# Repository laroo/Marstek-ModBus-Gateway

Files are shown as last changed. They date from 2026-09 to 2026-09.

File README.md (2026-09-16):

# Marstek ModBus Gateway



  

**Direct Ethernet-to-Modbus integration for Marstek battery systems, providing local monitoring and control via MQTT**

Marstek ModBus Gateway is a custom hardware gateway designed to bridge the Marstek Venus E v2.0 home battery energy storage system with Home Assistant and local automation systems via a hardwired Ethernet connection. Powered by an ESP32-ETH01 microcontroller and an RS485 transceiver, this dedicated PCB reads Modbus telemetry directly from the battery and translates it into MQTT messages for low-latency, cloud-free monitoring and active charge/discharge control.

## Key Features

- Hardwired Reliability: Utilizes the onboard Ethernet interface of the ESP32-ETH01 for fast, stable network communication without Wi-Fi dropouts.

- Direct Modbus to MQTT: Communicates with the Marstek Venus E v2.0 via RS485/Modbus RTU and publishes metrics and control entities to your local MQTT broker.

- Home Assistant Integration: Enables automatic MQTT discovery for seamless setup of battery state of charge (SoC), power flow, and charge/discharge overrides within Home Assistant.

- Compact Custom PCB: Integrates power regulation, RS485 transceiver protection/isolation, and clean mounting for the ESP32-ETH01 module.

## Technical Architecture

- MCU: ESP32-ETH01 (WT32-ETH01)

- Hardware Interface: RS485 (Modbus RTU)

- Network Protocol: Ethernet / MQTT (with Home Assistant MQTT Discovery)

- Target Device: Marstek Venus E v2.0 Battery System

## Primary Use Cases

- Off-peak grid charging and peak-shaving automated via Home Assistant MQTT triggers.

- Solar excess storage optimization and real-time power steering.

- Local telemetry logging and full battery management without relying on vendor cloud APIs.

## Changelog

v1.0
- Initial release

## MQTT Configuration

### MQTT Topics

TBD - will be updated when the gateway is fully implemented

```
marstek-modbus-gateway/state = CHARGING
```

### MQTT Commands

TBD - will be updated when the gateway is fully implemented

```
marstek-modbus-gateway/command = CHARGE
marstek-modbus-gateway/command = DISCHARGE
marstek-modbus-gateway/command = PAUSE
```

## Home Assistant Configuration

TODO

## Schematics and PCB

Used LibrePCB to design the schematics and PCB.

Schematic

PCB

Gerber files for the PCB can be found [here](librepcb/output/v1.0/gerber).

# Input/Output

| Pin | Direction | Function | Note |
|----|---|---|---|
| GPIO 2 | Input | Sensor 1 | Optional sensor |

## Code

The firmware is built on the Arduino framework using PlatformIO and implements a robust gate control system with the following key features:

- **MQTT Integration**: Remote control and status monitoring via MQTT over Ethernet (W5500)
- **Visual Feedback**: LED system indicating communication status
- **ModBus**: RS485 communication for industrial automation
- **Diagnostics**: Serial output at 115200 baud for debugging and monitoring

### Platform IO Setup

```
pyenv local 3.13
python -m venv .venv
source .venv/bin/activate
pip install -r requirements.txt
```

### Build

```
pio run
```

### Test

```
pio test -v -e native
```

Run a single test:

```
TEST_FILTER=test_mytest pio test -v -e native
```

### Upload (Serial)

```
pio run --target upload -v
```

### Wokwi Simulation

The firmware can be simulated using Wokwi.

#### Installation

To install the Wokwi CLI:

```
curl -L https://wokwi.com/ci/install.sh | sh
```

#### Running the Simulation

To run the simulation:

Build the ESP32 firmware for Wokwi:

```
pio run --environment esp32_wokwi
```

Build custom RS485 chip:

```
wokwi-cli chip compile wokwi/max485-marstek.chip.c
```

Run simulation:

```
wokwi-cli wokwi
```

Run linter:

```
wokwi-cli lint wokwi
```

### OTA (Over-the-Air) Update

The firmware includes [ElegantOTA](https://github.com/ayushsharma82/ElegantOTA) for wireless firmware updates over the network.

1. Open a browser and navigate to `http://<device-ip>/update`
2. Authenticate with the configured `OTA_USERNAME` and `OTA_PASSWORD`
3. Select the firmware binary (`.pio/build/esp32/firmware.bin`) and upload

OTA credentials are set as compile-time build flags in `private_config.ini`:

```ini
'-D OTA_USERNAME=youruser'
'-D OTA_PASSWORD=yourpassword'
```

### Web Interface

The device runs an HTTP server on port 80 with the following endpoints:

| Endpoint | Description |
|---|---|
| `/` | Device identification |

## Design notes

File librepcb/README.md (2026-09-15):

# My first pcb

## Description

This is a [LibrePCB](https://librepcb.org) project!
Just edit this file to add a description about it.

## License

No license set.

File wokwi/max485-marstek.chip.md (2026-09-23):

# MAX485 Marstek emulator chip

Wokwi custom chip that emulates the Modbus RTU slave side of a **Marstek Venus E v2.0** battery system behind an RS-485 transceiver.

## Build

```bash
wokwi-cli chip compile wokwi/max485-marstek.chip.c
```

## Run simulation

```bash
# Build the ESP32 firmware for Wokwi first
pio run --environment esp32_wokwi

# Compile and run the custom chip simulation
wokwi-cli chip compile wokwi/max485-marstek.chip.c
wokwi-cli wokwi
```

## Supported Modbus registers

Function code **0x03** (Read Holding Registers) and **0x06** (Write Single Register) are implemented.

| Register (DEC) | Register (HEX) | Name | Type | Implemented | Notes |
|---|---|---|---|---|---|
| 31000 | `0x7918` | Device name | `char[20]` | Yes | Returns `"BI_2.5_2.5"` padded with zeros; read quantity must be `10` registers |
| 30400 | `0x76C0` | Software version | `u16`, 0.01 | Yes | Returns `0x0067` (103 -> 1.03); read quantity must be `1` |
| 30401 | `0x76C1` | Firmware version | `u16` | Yes | Returns `0x0099` (153); read quantity must be `1` |
| 30402 | `0x76C2` | Device MAC address | `char[12]` | Yes | Returns `"A1B2C3D4E5F6"`; read quantity must be `6` registers |
| 42000 | `0xA410` | RS485 control mode | `u16` | Yes | R/W: `0x55AA` enable, `0x55BB` disable |
| 42010 | `0xA41A` | Forcible charge/discharge | `u16` | Yes | R/W: `0` stop, `1` charge, `2` discharge |
| 42020 | `0xA424` | Forcible charge power | `u16`, W | Yes | R/W: `0-2500` |
| 42021 | `0xA425` | Forcible discharge power | `u16`, W | Yes | R/W: `0-2500` |
| 32200 | `0x7DC8` | AC voltage | `u16`, 0.1 V | Yes | Returns `2300` (230.0 V); supports quantity `1` or `5` |
| 32201 | `0x7DC9` | AC current | `u16`, 0.01 A | Yes | Magnitude calculated from active power / 230 V |
| 32202 | `0x7DCA` | AC power | `s32`, W | Yes | Negative when charging, positive when discharging; based on forced power setting |
| 32204 | `0x7DCC` | AC frequency | `u16`, 0.01 Hz | Yes | Returns `5000` (50.00 Hz) |
| 32100 | `0x7D64` | Battery voltage (average) | `u16`, 0.01 V | Yes | Returns `5120` (51.20 V); supports quantity `1` or `4` |
| 32101 | `0x7D65` | Battery current (average) | `s16`, 0.01 A | Yes | Returns `1502` (15.02 A); read quantity must be `1` |
| 32102 | `0x7D66` | Battery power | `s32`, 1 W | Yes | Returns `2500` W; spans registers `32102` and `32103`; read quantity must be `2` |

Reading address `0x7D64` with quantity `4` returns voltage, current and power in a single response (registers `32100..32103`).

## Serial commands (ESP32 firmware)

The ESP32 firmware (`src/Marstek-ModBus-Gateway.ino.cpp`) accepts these commands over USB serial:

| Command | Action |
|---|---|
| `charge=<watts>` | Enable RS485 control mode, set charge power, start charging |
| `discharge=<watts>` | Enable RS485 control mode, set discharge power, start discharging |
| `charge=0` / `discharge=0` / `stop` | Stop charge/discharge and disable RS485 control mode |

Example: `charge=2000` writes `0x55AA` to `42000`, `2000` to `42020` and `1` to `42010`.

### LED feedback

- **Green LED** blips briefly on each successful Modbus telemetry poll and executed command.
- **Red LED** is solid while a Modbus or network error is present.
- LEDs are active-low.

## Findings and open issues

1. **Baud rate**: chip and ESP32 firmware are now both set to **115200 baud, 8N1**, matching the Marstek datasheet.
2. **Static/example values**: all register values are hard-coded examples taken from the CSV. Telemetry (voltage/current/power) does not yet change when charge/discharge control is active.
3. **FC 0x03 and FC 0x06 supported**: read holding registers and write single register are implemented. Other function codes (0x04, 0x10, etc.) return an illegal-function exception.
4. **RE/DE pins not emulated**: the chip does not model the MAX485 direction-control behaviour; it simply receives on `DI` and transmits on `RO`. This matches the Wokwi simulation because the ESP32 already drives RE/DE.
5. **CRC validation**: incoming frames are CRC-checked and responses include a valid Modbus RTU CRC-16.
6. **Firmware loop**: `src/Marstek-ModBus-Gateway.ino.cpp` reads telemetry every 4 s and processes serial commands (`charge=<watts>`, `discharge=<watts>`, `stop`) immediately.

## TODO — implement all function ID registers

Based on `specs/Modbus Table - Modbus Datasheet.csv`:

### Read holding registers (FC 0x03)

- [x] 31000 — Device name
- [x] 32100 — Battery voltage (average)
- [x] 32101 — Battery current (average)
- [x] 32102 — Battery power
- [ ] 30000..30010 — Average/grid measurements
- [ ] 30100, 30200, 30300..30303 — Status / WiFi / BT / Cloud
- [ ] 30399 — BMS version (same as 31102)
- [x] 30400, 30401, 30402 — Software/firmware version + MAC
- [ ] 30500..30800 — Misc status
- [ ] 31100..31102 — Soft/firmware/BMS version
- [ ] 31200 — SN code
- [ ] 32104, 32105 — Battery SoC / total energy
- [x] 32200..32204 — AC measurements
- [ ] 32300..32302 — AC off-grid measurements
- [ ] 33000..33010 — Energy counters
- [ ] 35000..35011 — Temperatures
- [ ] 35100 — Inverter state
- [ ] 35110..35112 — Charge/discharge limits
- [ ] 36000..36104 — Alarm / fault words
- [ ] 37000..37013 — Misc / cell information
- [ ] 41000, 41001, 41010, 41100, 41200, 41500, 41516 — Control / config
- [x] 42000, 42010..42021 — RS485 control / force charge-discharge
- [ ] 43000..43129 — Time-of-use settings
- [ ] 44000..44100, 45603, 45604 — Cutoff / grid standards / unknown

### Write functions

- [ ] FC 0x06 — Write single register (e.g. 41000 restart, 41100 Modbus address)
- [ ] FC 0x10 — Write multiple registers (e.g. time-of-use slots, WiFi credentials)

## Reference

- Modbus register table: `../specs/Modbus Table - Modbus Datasheet.csv`
- ESP32 firmware: `../src/Marstek-ModBus-Gateway.ino.cpp`

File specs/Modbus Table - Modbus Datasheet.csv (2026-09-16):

This document is based on ‘Duravolt Plug-In thuisbatterij 485 protocol v1.1’, available from https://duravolt.nl/wp-content/uploads/Duravolt-Plug-in-Battery-Modbus.pdf (checked on 14-08-2025). Changes made to the document are highlighted in red (except for typo’s). Scans are made on firmware v153 and BMS v213.
Protocol specification:
Standard Modbus RTU Protocol
Modbus default Address: 1
baud:115200, 8bit, No parity bit, 1bit Stopbit
Quirk: If register contains more than 2 bytes of data, data should be read in one function call instead of consecutive calls to consecutive registers or it will be invalid. Therefore if any data is present, one can deduct where a range must be split. If data is zeroes, the range is left and appended with a ‘?’.
Version | Date |  | Change
v2.0 | 07/11/25 |  | Create document based on Duravolt document
v2.1 | 07/16/25 |  | Added registers 30001, 30002, 30004, 30005, 30006, 30008, 30009, 30010, 30300, 30301, 30302, 30303, 37004, 37005, 37006, 37007, 37008, 41010. Added notes on 30007, 30100, 30600, 36101, 37013
v2.2 | 08/14/25 |  | Added observerations for some unknown registers. Changed error registers based on educated guesses. Identified register 41001. Added notes for registers 41500, 41516, 43000, 45603, 45604.
Function | ID (DEC) | ID (HEX) | Name | Bytes | Value type | Gain / Unit | Description | Read out | Meaning
0x03 | 30000 | 7530 | Unknown | 2 | unknown | unknown | 142-145 (DEC) osc, mostly 143-144, more activity 144-145 when charging
 | 30001 | 7531 | Battery voltage (average) | 2 | u16 | 0,01 V | Same as 32100 | 5120 (DEC) | 51,2 V
 | 30002 | 7532 | Battery current (average) | 2 | s16 | 0,01 A | Same as 32101 | 1502 (DEC) | 15,02 A
 | 30003 | 7533 | Unknown | 2 | unknown | unknown | Corresponds to AC Voltage added with Power?
 | 30004 | 7534 | AC voltage | 2 | u16 | 0,1 V | Same as 32200 | 2200 (DEC) | 220 V
 | 30005 | 7535 | AC current | 2 | u16 | 0,01 A | Same as 32201 | 350 (DEC) | 3,5 A
 | 30006 | 7536 | AC offgrid voltage | 2 | u16 | 0,1 V | Same as 32300 | 2200 (DEC) | 220 V
 | 30007 | 7537 | Unknown | 2 | unknown | unknown | Related to status? Rapid osc. between 1 and 2 when charge, 1 when backup, 0 when idle. Also random osc. between 0 and 1 when idle
 | 30008 | 7538 | Internal MOS1 temperature | 2 | s16 | 0,1 °C | Same as 35001 | 257 (DEC) | 25,7 °C
 | 30009 | 7539 | Internal MOS2 temperature | 2 | s16 | 0,1 °C | Same as 35002 | 257 (DEC) | 25,7 °C
 | 30010 | 753A | Internal temperature | 2 | s16 | 0,1 °C | Same as 35000 | 373 (DEC) | 37,3 °C
 | 30100 | 7594 | Unknown | 8? | unknown | unknown | Same as 36100
 | 30200 | 75F8 | Unknown | 8? | unknown | unknown | Always seen 0
 | 30300 | 765C | WiFi status | 2 | u16 | / | 0:disconnected, 1:connected
 | 30301 | 765D | BT status | 2 | u16 | / | 0:off, 1:active_after_boot?stand-by?, 2:connected, 3:active
 | 30302 | 765E | Cloud status | 2 | u16 | / | 0:disconnected, 1:connected, Approx 5 min delay after connection loss
 | 30303 | 765F | WiFi Signal Strength | 2 | u16 | dBm
 | 30399 | 76BF | BMS version (HEX) | 2 | u16 | / | Same as 31102 (but in HEX) | 0xD5 (HEX) | 213
 | 30400 | 76C0 | Software version (HEX) | 2 | u16 | 0,01 | Same as 31100 (but in HEX) | 0x67 (HEX) | 1,03
 | 30401 | 76C1 | Firmware version (HEX) | 2 | u16 | / | Same as 31101 (but in HEX) | 0x99 (HEX) | 153
 | 30402 | 76C2 | Device MAC address | 12 | char | /
 | 30500 | 7724 | Unknown | 2 | unknown | unknown | Always seen 1
 | 30600 | 7788 | Unknown | 2 | unknown | unknown | 00Ca when idle, 00cc/00cb when bypass, 0xd4 when backup, 00ce when (dis)charge, sometime 0xd7 when empty followed by charge, or 0xd8
 | 30700 | 77EC | Unknown | 2 | unknown | unknown | Changed to 1 some time after empty and stayed 1 even after full. Turned 0 after messing around when 100 soc, self-test fault?
 | 30800 | 7850 | Communication module firmware version | 12 | char | /
 | 31000 | 7918 | Device name | 20 | char | / | Typically: BI_2.5_2.5 or AC01
 | 31100 | 797C | Soft version | 2 | u16 | 0,01 |  | 103 (DEC) | 1,03
 | 31101 | 797D | Firmware version | 2 | u16 | / |  | 153 (DEC) | 153
 | 31102 | 797E | BMS version | 2 | u16 | / |  | 213 (DEC) | 213
 | 31200 | 79E0 | SN code | 20 | char | / | Typically: [empty]
 | 32100 | 7D64 | Battery voltage (average) | 2 | u16 | 0,01 V |  | 5120 (DEC) | 51,2 V
 | 32101 | 7D65 | Battery current (average) | 2 | s16 | 0,01 A |  | 1502 (DEC) | 15,02 A
 | 32102 | 7D66 | Battery power | 4 | s32 | 1 W |  | 2500 (DEC) | 2500 W
 | 32104 | 7D68 | Battery SOC | 2 | u16 | 1 % |  | 500 (DEC) | 50 %
 | 32105 | 7D69 | Battery total energy | 2 | u16 | 0,001 kWh | Unit: v148: 0.001 / v147: 0.01 | 2500 (DEC) | 2,5 kWh
 | 32200 | 7DC8 | AC voltage | 2 | u16 | 0,1 V |  | 2200 (DEC) | 220 V
 | 32201 | 7DC9 | AC current | 2 | u16 | 0,01 A |  | 350 (DEC) | 3,5 A
 | 32202 | 7DCA | AC power | 4 | s32 | W | Positive value means feeds power into the grid | 1000 (DEC) | 1000 W
 | 32204 | 7DCC | AC frequency | 2 | u16 | 0,01 Hz |  | 5000 (DEC) | 50 Hz
 | 32300 | 7E2C | AC offgrid voltage | 2 | u16 | 0,1 V |  | 2200 (DEC) | 220 V
 | 32301 | 7E2D | AC offgrid current | 2 | u16 | 0,1 A |  | 350 (DEC) | 3,5 A
 | 32302 | 7E2E | AC offgrid power | 4 | s32 | W |  | 1000 (DEC) | 1000 W
 | 33000 | 80E8 | Total charging energy | 4 | u32 | 0,01 kWh |  | 100000 (DEC) | 1000 kWh
 | 33002 | 80EA | Total discharging energy | 4 | u32 | 0,01 kWh |  | 100000 (DEC) | 1000 kWh
 | 33004 | 80EC | Daily charging energy | 4 | u32 | 0,01 kWh | Updated daily at 00:00 | 500 (DEC) | 5 kWh
 | 33006 | 80EE | Daily discharging energy | 4 | u32 | 0,01 kWh | Updated daily at 00:00 | 2000 (DEC) | 20 kWh
 | 33008 | 80F0 | Monthly charging energy | 4 | u32 | 0,01 kWh | Updated on 1st of each month | 10000 (DEC) | 100 kWh
 | 33010 | 80F2 | Monthly discharging energy | 4 | u32 | 0,01 kWh | Updated on 1st of each month | 10000 (DEC) | 100 kWh
 | 35000 | 88B8 | Internal temperature | 2 | s16 | 0,1 °C |  | 373 (DEC) | 37,3 °C
 | 35001 | 88B9 | Internal MOS1 temperature | 2 | s16 | 0,1 °C |  | 257 (DEC) | 25,7 °C
 | 35002 | 88BA | Internal MOS2 temperature | 2 | s16 | 0,1 °C |  | 257 (DEC) | 25,7 °C
 | 35010 | 88C2 | Max cell temperature | 2 | s16 | 0,1 °C | Unit: BMS v213: 1°C | -32 (DEC) | -3,2 °C
 | 35011 | 88C3 | Min cell temperature | 2 | s16 | 0,1 °C | Unit: BMS v213: 1°C | 400 (DEC) | 40 °C
 | 35100 | 891C | Inverter state | 2 | u16 | / | 0:sleep, 1:stand-by, 2:charge, 3:discharge, 4:backup mode, 5:OTA upgrade, 6:bypass | 2 | Charge
 | 35110 | 8926 | Battery charge voltage limit | 2 | u16 | 0,1 V | Typically: 57,1 V | 120 (DEC) | 12 V
 | 35111 | 8927 | Battery charge current limit | 2 | u16 | 0,1 A |  | 50 (DEC) | 5 A
 | 35112 | 8928 | Battery discharge current limit | 2 | u16 | 0,1 A |  | 50 (DEC) | 5 A
 | 36000 | 8CA0 | Unknown | 2 | unknown | unknown | Alarm/fault register
 | 36001 | 8CA1 | Unknown | 2 | unknown | unknown | Alarm/fault register
 | 36100 | 8D04 | Alarm word | 2 | bit | / | See below (educated guess, see notes below)
 |  |  | PLL Abnormal restart | 0 | bit | / | 0:normal, 1:abnormal
 |  |  | Overtemperature limit | 1 | bit | / | 0:normal, 1:abnormal
 |  |  | Low temperature limit | 2 | bit | / | 0:normal, 1:abnormal
 |  |  | Fan abnormal warning | 3 | bit | / | 0:normal, 1:abnormal
 |  |  | Low battery SoC warning | 4 | bit | / | 0:normal, 1:abnormal
 |  |  | Output overcurrent warning | 5 | bit | / | 0:normal, 1:abnormal
 |  |  | Abnormal line sequence detection | 6 | bit | / | 0:normal, 1:abnormal
 | 36101 | 8D05 | Fault word | 2 | bit | / | See below (educated guess, see notes below)
 |  |  | Hardware bus overvoltage | 0 | bit | / | 0:normal, 1:abnormal
 |  |  | Hardware output overcurrent | 1 | bit | / | 0:normal, 1:abnormal
 |  |  | Hardware trans overcurrent | 2 | bit | / | 0:normal, 1:abnormal
 |  |  | Hardware battery overcurrent | 3 | bit | / | 0:normal, 1:abnormal
 |  |  | Hardware protection | 4 | bit | / | 0:normal, 1:abnormal
 |  |  | Output overcurrent warning | 5 | bit | / | 0:normal, 1:abnormal
 |  |  | High voltage bus overvoltage | 6 | bit | / | 0:normal, 1:abnormal
 |  |  | High voltage bus undervoltage | 7 | bit | / | 0:normal, 1:abnormal
 |  |  | Overpower protection | 8 | bit | / | 0:normal, 1:abnormal
 |  |  | FSM abnormal | 9 | bit | / | 0:normal, 1:abnormal
 |  |  | Overtemperature protection | 10 | bit | / | 0:normal, 1:abnormal
 |  |  | Inverter soft start timeout | 11 | bit | / | 0:normal, 1:abnormal
 | 36102 | 8D06 | Unknown | 2 | unknown | unknown | Alarm/fault register
 | 36103 | 8D07 | Fault word | 1 | bit | / | See below (educated guess, see notes below)
 |  |  | Battery overvoltage | 0 | bit | / | 0:normal, 1:abnormal
 |  |  | Battery undervoltage | 1 | bit | / | 0:normal, 1:abnormal
 |  |  | Battery overcurrent | 2 | bit | / | 0:normal, 1:abnormal
 |  |  | Battery low SoC | 3 | bit | / | 0:normal, 1:abnormal
 |  |  | Battery communication failure | 4 | bit | / | 0:normal, 1:abnormal
 |  |  | BMS protect | 5 | bit | / | 0:normal, 1:abnormal
 | The registers below are from the original documentation and kept as reference until we are definitely sure how the registers work
 | 36000 | 8CA0 | Alarm word | 2 | bit | / | See below (probably incorrect!)
 |  |  | PLL Abnormal restart | 0 | bit | / | 0:normal, 1:abnormal
 |  |  | Overtemperature limit | 1 | bit | / | 0:normal, 1:abnormal
 |  |  | Low temperature limit | 2 | bit | / | 0:normal, 1:abnormal
 |  |  | Fan abnormal warning | 3 | bit | / | 0:normal, 1:abnormal
 |  |  | Low battery SoC warning | 4 | bit | / | 0:normal, 1:abnormal
 |  |  | Output overcurrent warning | 5 | bit | / | 0:normal, 1:abnormal
 |  |  | Abnormal line sequence detection | 6 | bit | / | 0:normal, 1:abnormal
 | 36001 | 8CA1 | Fault word | 2 | bit | / | See below (probably incorrect!)
 |  |  | WiFi abnormal | 0 | bit | / | 0:normal, 1:abnormal
 |  |  | BLE abnormal | 1 | bit | / | 0:normal, 1:abnormal
 |  |  | Network abnormal | 2 | bit | / | 0:normal, 1:abnormal
 |  |  | CT connection abnormal | 3 | bit | / | 0:normal, 1:abnormal
 | 36100 | 8D04 | Fault word | 2 | bit | / | See below (probably incorrect!)
 |  |  | Grid overvoltage | 0 | bit | / | 0:normal, 1:abnormal
 |  |  | Grid undervoltage | 1 | bit | / | 0:normal, 1:abnormal
 |  |  | Grid overfrequency | 2 | bit | / | 0:normal, 1:abnormal
 |  |  | Grid underfrequency | 3 | bit | / | 0:normal, 1:abnormal
 |  |  | Grid peak voltage abnormal | 4 | bit | / | 0:normal, 1:abnormal 36100[4]=1 some time after empty (low SoC/undervoltage?), so might be 36000
 |  |  | Current Dcover | 5 | bit | / | 0:normal, 1:abnormal
 |  |  | Voltage Dcover | 6 | bit | / | 0:normal, 1:abnormal
 | 36101 | 8D05 | Fault word | 1 | bit | / | See below (probably incorrect!) 36101[7]=1 when grid loss, but doesn’t trigger when booted w/ grid = probably ondervoltage
 |  |  | Battery overvoltage | 0 | bit | / | 0:normal, 1:abnormal
 |  |  | Battery undervoltage | 1 | bit | / | 0:normal, 1:abnormal
 |  |  | Battery overcurrent | 2 | bit | / | 0:normal, 1:abnormal
 |  |  | Battery low SoC | 3 | bit | / | 0:normal, 1:abnormal
 |  |  | Battery communication failure | 4 | bit | / | 0:normal, 1:abnormal
 |  |  | BMS protect | 5 | bit | / | 0:normal, 1:abnormal
 | 36102 | 8D06 | Unknown | 2 | unknown | unknown
 | 36103 | 8D07 | Fault word | 2 | bit | / | See below (probably incorrect!)
 |  |  | Hardware bus overvoltage | 0 | bit | / | 0:normal, 1:abnormal
 |  |  | Hardware output overcurrent | 1 | bit | / | 0:normal, 1:abnormal
 |  |  | Hardware trans overcurrent | 2 | bit | / | 0:normal, 1:abnormal
 |  |  | Hardware battery overcurrent | 3 | bit | / | 0:normal, 1:abnormal changes to 1 sometimes when empty, so probably aligns with 36101
 |  |  | Hardware protection | 4 | bit | / | 0:normal, 1:abnormal changes to 1 sometimes when empty, so probably aligns with 36101
 |  |  | Output overcurrent warning | 5 | bit | / | 0:normal, 1:abnormal
 |  |  | High voltage bus overvoltage | 6 | bit | / | 0:normal, 1:abnormal
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

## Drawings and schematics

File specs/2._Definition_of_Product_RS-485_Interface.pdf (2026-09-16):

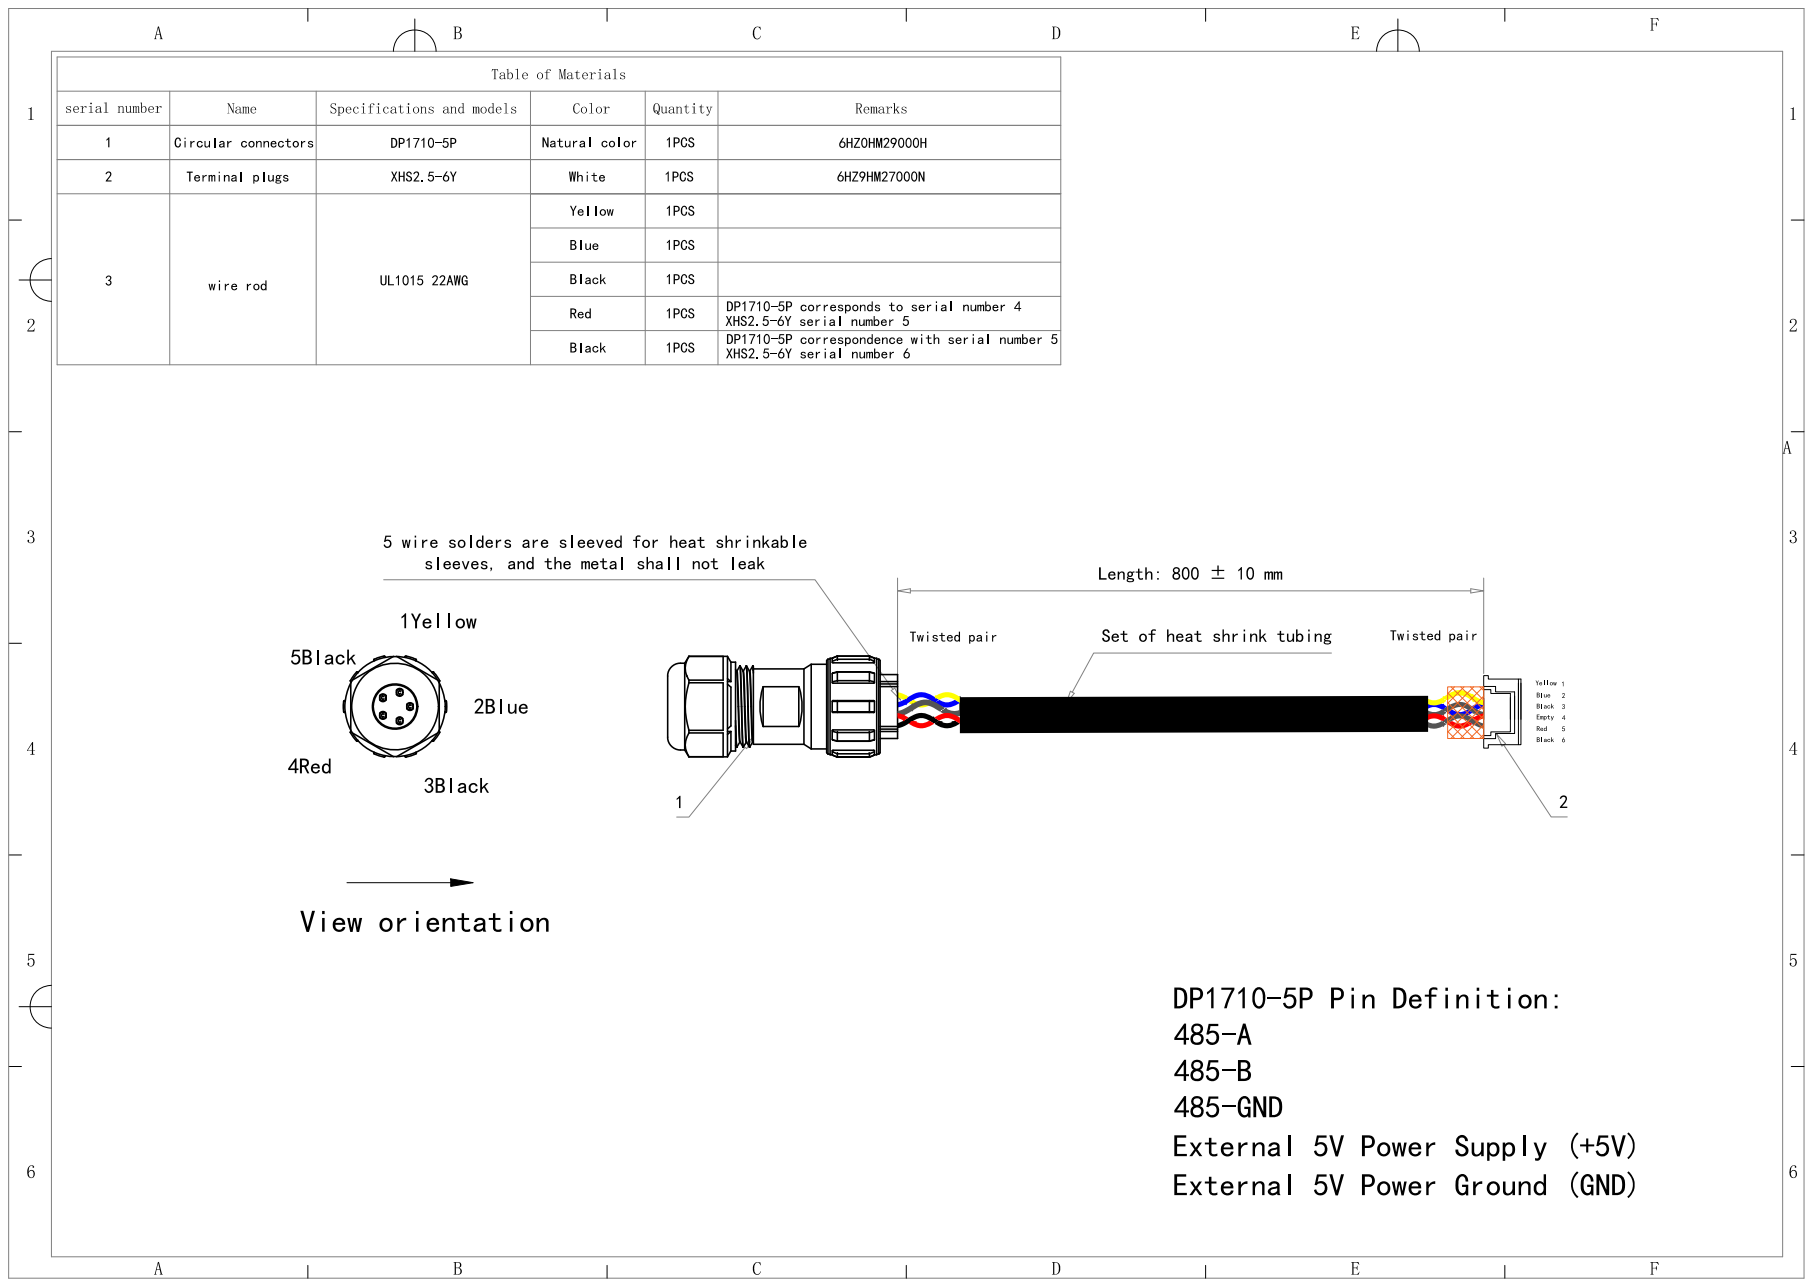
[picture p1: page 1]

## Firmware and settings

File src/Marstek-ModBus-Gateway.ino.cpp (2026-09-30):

/**
 * Marstek ModBus Gateway
 *
 * ESP32-ETH01 (WT32-ETH01) bridge between a Marstek Venus-E battery
 * (RS485 / Modbus RTU) and the local network:
 *   - MQTT telemetry publishing and command input
 *   - Web dashboard with controls + ElegantOTA
 *   - LED status indicators (green = Modbus activity, red = error)
 *   - Serial diagnostics at 115200 baud
 *
 * Serial commands: charge=<watts>, discharge=<watts>, stop
 */

#include "Arduino.h"
#include <PubSubClient.h>
#include <arduino-timer.h>
#include <EthernetESP32.h>
#include <WiFi.h>
#include <WebServer.h>
#include <ElegantOTA.h>
#include <SPI.h>
#include <Network.h>

#include "config.h"
#include "marstek.h"
#include "ledmanager.h"
#include "mqttmanager.h"
#include "webmanager.h"

// WT32-ETH01 internal LAN8720 PHY pins: MDC=23, MDIO=18, power=16
EMACDriver driver(ETH_PHY_LAN8720, 23, 18, 16);

EthernetClient ethClient;
WiFiClient wifiClient;

// Pointer to the active client (Ethernet or WiFi)
NetworkClient* activeClient = nullptr;

// Connection check result (used by network event handler)
int connectionStatus = 0;

// ============================================================================
// CONFIGURATION STRUCTURE
// ============================================================================
struct Config {
  char clientId[32]; // Random client ID generated at startup

  // Timing Settings
  unsigned long telemetryInterval = 4000;  // Modbus telemetry poll interval
  unsigned long publishInterval = 10000;   // MQTT status publish interval

  // GPIO Pins (active-low LEDs, per PCB schematic)
  int redLedPin = 17;
  int greenLedPin = 5;
};

// ============================================================================
// GLOBAL VARIABLES
// ============================================================================
Config config;
Marstek *marstek = nullptr;
LEDManager *ledManager = nullptr;
MQTTManager *mqttManager = nullptr;

// Timer for main loop management
auto mainTimer = timer_create_default();

// ============================================================================
// NETWORK EVENT HANDLER
// ============================================================================
// WARNING: This function is called from a separate FreeRTOS task (thread)!
void onNetworkEvent(arduino_event_id_t event, arduino_event_info_t info) {
  Serial.printf("[Network-event] event: %d\n", event);

  switch (event) {
    case ARDUINO_EVENT_ETH_START:
      Serial.println("[ETH] Ethernet started");
      break;
    case ARDUINO_EVENT_ETH_STOP:
      Serial.println("[ETH] Ethernet stopped");
      break;
    case ARDUINO_EVENT_ETH_CONNECTED:
      Serial.println("[ETH] Ethernet connected - Link UP");
      break;
    case ARDUINO_EVENT_ETH_DISCONNECTED:
      Serial.println("[ETH] Ethernet disconnected - Link DOWN");
      connectionStatus = 0;
      activeClient = nullptr;
      break;
    case ARDUINO_EVENT_ETH_GOT_IP:
      Serial.print("[ETH] Obtained IP address: ");
      Serial.println(IPAddress(info.got_ip.ip_info.ip.addr));
      Serial.print("[ETH] Gateway: ");
      Serial.println(IPAddress(info.got_ip.ip_info.gw.addr));
      Serial.print("[ETH] Netmask: ");
      Serial.println(IPAddress(info.got_ip.ip_info.netmask.addr));
      connectionStatus = 1;
      activeClient = &ethClient;
      break;
    case ARDUINO_EVENT_ETH_GOT_IP6:
      Serial.println("[ETH] Ethernet IPv6 is preferred");
      break;
    case ARDUINO_EVENT_WIFI_STA_START:
      Serial.println("[WiFi] WiFi client started");
      break;
    case ARDUINO_EVENT_WIFI_STA_STOP:
      Serial.println("[WiFi] WiFi client stopped");
      break;
    case ARDUINO_EVENT_WIFI_STA_CONNECTED:
      Serial.println("[WiFi] Connected to access point");
      break;
    case ARDUINO_EVENT_WIFI_STA_DISCONNECTED:
      Serial.println("[WiFi] Disconnected from WiFi access point");
      if (connectionStatus == 2) {
        connectionStatus = 0;
        activeClient = nullptr;
      }
      break;
    case ARDUINO_EVENT_WIFI_STA_GOT_IP:
      Serial.print("[WiFi] Obtained IP address: ");
      Serial.println(IPAddress(info.got_ip.ip_info.ip.addr));
      connectionStatus = 2;
      activeClient = &wifiClient;
      break;
    case ARDUINO_EVENT_WIFI_STA_LOST_IP:
      Serial.println("[WiFi] Lost IP address");
      if (connectionStatus == 2) {
        connectionStatus = 0;
        activeClient = nullptr;
      }
      break;
    default:
      break;
  }
}

// ============================================================================
// FUNCTION DECLARATIONS
// ============================================================================
int checkConnection();
bool checkConnectionCallback(void *);
bool reportConnectionStatusCallback(void *);
NetworkClient* getActiveClient();
void pumpServices();

// ============================================================================
// SETUP FUNCTION
// ============================================================================
void setup() {
  // Initialize serial communication at 115200 baud
  Serial.begin(115200);
  delay(100); // Allow serial to initialize

  Serial.println("[INIT] Marstek ModBus Gateway starting...");
  Serial.print("[INIT] Free heap: ");
  Serial.print(ESP.getFreeHeap());
  Serial.println(" bytes");

  // Generate random client ID for MQTT
  randomSeed(analogRead(0));
  sprintf(config.clientId, "marstek_gw_%06X", random(0xFFFFFF));
  Serial.print("[INIT] MQTT Client ID: ");
  Serial.println(config.clientId);

  // Initialize LED Manager
  ledManager = new LEDManager(config.redLedPin, config.greenLedPin);
  if (ledManager) {
    ledManager->initialize();
    Serial.println("[INIT] LED manager initialized");
  } else {
    Serial.println("[ERROR] Failed to initialize LED manager");
  }

  // Initialize Marstek Modbus controller
  marstek = new Marstek();
  if (marstek) {
    marstek->initialize(config.telemetryInterval);
    // Keep web/MQTT/LEDs responsive while blocking on Modbus replies
    marstek->setIdleCallback(pumpServices);
    Serial.println("[INIT] Marstek controller created and initialized");
  } else {
    Serial.println("[ERROR] Failed to create Marstek controller");
  }

  // Register network event listener
  Network.onEvent(onNetworkEvent);
  Serial.println("[INIT] Network event listener registered");

  Ethernet.init(driver);

  Serial.println("Initialize Ethernet with DHCP:");
  if (Ethernet.begin()) {
    Serial.print("  DHCP assigned IP ");
    Serial.println(Ethernet.localIP());
  } else {
    Serial.println("Failed to configure Ethernet using DHCP");
  }

  // Check for Ethernet hardware present
  if (Ethernet.hardwareStatus() == EthernetNoHardware) {
    Serial.println("Ethernet hardware was not found.");
  }
  if (Ethernet.linkStatus() == LinkOFF) {
    Serial.println("Ethernet cable is not connected.");
  }

  // Initialize MQTT Manager
  mqttManager = new MQTTManager(MQTT_BROKER, MQTT_PORT,
                                config.clientId, MQTT_TOPIC_STATUS,
                                MQTT_TOPIC_COMMAND, MQTT_USERNAME, MQTT_PASSWORD);
  if (mqttManager) {
    mqttManager->initialize(activeClient);

    // Set Marstek controller reference for telemetry and command handling
    if (marstek) {
      mqttManager->setMarstekController(marstek);
    }

    Serial.println("[INIT] MQTT manager initialized");
  } else {
    Serial.println("[ERROR] Failed to initialize MQTT manager");
  }

  Serial.println("[INIT] Setting up web server...");
  setupWebServer(config.clientId);

  // Schedule connection check every 5 seconds
  mainTimer.every(5000, checkConnectionCallback);
  Serial.println("[INIT] Connection check scheduled every 5 seconds");

  // Schedule connection status reporting every 5 seconds
  mainTimer.every(5000, reportConnectionStatusCallback);
  Serial.println("[INIT] Connection status reporting scheduled every 5 seconds");

  Serial.println("[INIT] System initialization complete");
  Serial.println("[INIT] Commands: charge=<watts>, discharge=<watts>, stop");
  Serial.println("======================================");
}

// Timer callback for connection checking
bool checkConnectionCallback(void *) {
  connectionStatus = checkConnection();
  return true; // Repeat the timer
}

// Timer callback for reporting connection status
bool reportConnectionStatusCallback(void *) {
  if (connectionStatus == 1) {
    Serial.println("Connected to Ethernet");
  }
  else if (connectionStatus == 2) {
    Serial.println("Connected to Wi-Fi");
  }
  else {
    Serial.println("Not Connected");
  }
  return true; // Repeat the timer
}

int checkConnection() {
  // Check if Ethernet is available
  if (ethClient.connected() && (Ethernet.linkStatus() == LinkON)) {
    activeClient = &ethClient;
    return 1;
  }
  else if (Ethernet.linkStatus() == LinkON) {
    // Use Ethernet connection
    if (!ethClient.connected()) {
      Serial.println("Connecting via Ethernet...");
      if (WiFi.status() == WL_CONNECTED) {
        WiFi.disconnect();
      }
      activeClient = &ethClient;
      return 1;
    }
  }

  if (WiFi.status() == WL_CONNECTED) {
    activeClient = &wifiClient;
    return 2;
  }

  // Use Wi-Fi connection (Wokwi simulation has no Ethernet)
  WiFi.begin("Wokwi-GUEST", "", 6);
  Serial.println("Connecting via Wi-Fi...");
  for (int i = 0; i < 50; i++) {
    if (WiFi.status() == WL_CONNECTED) {
      Serial.println(" CONNECTED");
      break;
    }
    delay(100);
    Serial.print(".");
  }

  if (WiFi.status() == WL_CONNECTED) {
    Serial.println("Connected to Wi-Fi");
    activeClient = &wifiClient;
    return 2;
  }

  Serial.println("Wi-Fi not Connected");
  activeClient = nullptr;
  return 0;
}

// ============================================================================
// MAIN LOOP
// ============================================================================
void loop() {

  // Handle serial commands
  if (Serial.available()) {
    String cmd = Serial.readStringUntil('\n');
    cmd.trim();
    if (cmd.length() > 0 && marstek) {
      if (marstek->handleCommand(cmd) && ledManager) {
        ledManager->flashGreen();
      }
    }
  }

  // Update Marstek controller (polls telemetry on interval)
  if (marstek) {
    if (marstek->update() && ledManager) {
      ledManager->flashGreen();
    }
  }

  // Network-dependent services
  if (activeClient && connectionStatus > 0) {
    loopWebServer();

    // Update MQTT manager
    if (mqttManager) {
      mqttManager->setClient(activeClient);
      mqttManager->update();
    }
  }

  // Error indicator: red while Modbus unhealthy or no network
  if (ledManager) {
    bool modbusError = marstek && !marstek->isHealthy();
    bool networkError = connectionStatus == 0;
    ledManager->setError(modbusError || networkError);
    ledManager->update();
  }

  // Tick main timer for any scheduled tasks
  mainTimer.tick();

  // Small delay to prevent excessive CPU usage
  delay(10);
}

// ============================================================================
// GET ACTIVE CLIENT
// ============================================================================
/**
 * Returns a pointer to the active network client (Ethernet or WiFi)
 * based on the current connection status.
 *
 * @return NetworkClient* Pointer to active client, or nullptr if no connection
 */
NetworkClient* getActiveClient() {
  return activeClient;
}

// ============================================================================
// SERVICE PUMP (Modbus idle callback)
// ============================================================================
/**
 * Services network/LED duties while Marstek blocks waiting for a Modbus
 * reply (called via ModbusMaster's idle callback from inside
 * marstek->update()). Keeps the web server and MQTT responsive even when
 * the RS485 bus is dead.
 */
void pumpServices() {
  if (activeClient && connectionStatus > 0) {
    loopWebServer();
    if (mqttManager) {
      mqttManager->setClient(activeClient);
      mqttManager->update();
    }
  }
  if (ledManager) {
    ledManager->update();
  }
}

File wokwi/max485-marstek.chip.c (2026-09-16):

// Wokwi Custom Chip - Marstek Venus E v2.0 Modbus RTU Slave Emulator
//
// Emulates the Modbus RTU protocol of a Marstek Venus E v2.0 battery
// system behind an RS-485 transceiver. The chip receives Modbus RTU
// requests over UART and responds with the requested register data.
//

#include "wokwi-api.h"
#include <stdio.h>
#include <stdlib.h>
#include <stdint.h>
#include <string.h>

#define MODBUS_SLAVE_ID 1

// Marstek Venus E v2.0 default: 115200 baud, 8N1.
// Must stay in sync with the ESP32 firmware.
#define MODBUS_BAUD_RATE 115200

// 3.5 character time at the configured baud rate (microseconds).
// At 115200 baud this is ~0.3 ms; use a slightly larger threshold.
#define MODBUS_INTER_FRAME_US 500

typedef struct {
  uart_dev_t uart0;
  uint8_t modbusBuffer[256];
  uint16_t bufferIndex;
  uint64_t last_byte_time;
  // RS485 control registers (42000..42021)
  uint16_t control_mode;      // 42000: 0x55AA enabled, 0x55BB disabled
  uint16_t force_mode;        // 42010: 0=stop, 1=charge, 2=discharge
  uint16_t charge_power;      // 42020 W
  uint16_t discharge_power;   // 42021 W
} chip_state_t;


static void on_uart_rx_data(void *user_data, uint8_t byte);
static void on_uart_write_done(void *user_data);
static void chip_timer_callback(void *user_data);

void chip_init(void) {
  chip_state_t *chip = malloc(sizeof(chip_state_t));

  const uart_config_t uart_config = {
    .tx = pin_init("RO", INPUT_PULLUP),
    .rx = pin_init("DI", INPUT),
    .baud_rate = MODBUS_BAUD_RATE,
    .rx_data = on_uart_rx_data,
    .write_done = on_uart_write_done,
    .user_data = chip,
  };
  chip->uart0 = uart_init(&uart_config);
  chip->bufferIndex = 0;
  chip->last_byte_time = 0;

  chip->control_mode = 0x55BB;
  chip->force_mode = 0;
  chip->charge_power = 0;
  chip->discharge_power = 0;

  const timer_config_t t_config = {
    .callback = chip_timer_callback,
    .user_data = chip,
  };

  timer_t timer = timer_init(&t_config);
  // Poll frequently enough to detect the end of a Modbus frame.
  timer_start(timer, 500, true);

  printf("MAX485/Marstek chip initialized at %d baud\n", MODBUS_BAUD_RATE);
}

// CRC-16 (Modbus RTU, polynomial 0x8005, init 0xFFFF)
static uint16_t modbus_crc16(const uint8_t *data, uint16_t length) {
  uint16_t crc = 0xFFFF;
  for (uint16_t i = 0; i < length; i++) {
    crc ^= data[i];
    for (uint8_t j = 0; j < 8; j++) {
      if (crc & 0x0001) {
        crc = (crc >> 1) ^ 0xA001;
      } else {
        crc >>= 1;
      }
    }
  }
  return crc;
}

static void send_modbus_response(uart_dev_t uart0, uint8_t slave_id,
                                  uint8_t function_code, const uint8_t *data,
                                  uint16_t data_length) {
  uint8_t response[256];
  uint16_t pos = 0;

  response[pos++] = slave_id;
  response[pos++] = function_code;
  response[pos++] = (uint8_t)data_length;
  for (uint16_t i = 0; i < data_length; i++) {
    response[pos++] = data[i];
  }

  uint16_t crc = modbus_crc16(response, pos);
  response[pos++] = crc & 0xFF;
  response[pos++] = (crc >> 8) & 0xFF;

  printf("[TX] %02X %02X (len=%u)\n", slave_id, function_code, data_length);
  uart_write(uart0, response, pos);
}

static void send_modbus_raw_response(uart_dev_t uart0, const uint8_t *data,
                                      uint16_t data_length) {
  uint8_t response[256];
  memcpy(response, data, data_length);

  uint16_t crc = modbus_crc16(data, data_length);
  response[data_length++] = crc & 0xFF;
  response[data_length++] = (crc >> 8) & 0xFF;

  printf("[TX] raw %02X %02X\n", data[0], data[1]);
  uart_write(uart0, response, data_length);
}

static void send_modbus_exception(uart_dev_t uart0, uint8_t slave_id,
                                   uint8_t function_code, uint8_t exception_code) {
  uint8_t response[5];
  response[0] = slave_id;
  response[1] = function_code | 0x80;
  response[2] = exception_code;

  uint16_t crc = modbus_crc16(response, 3);
  response[3] = crc & 0xFF;
  response[4] = (crc >> 8) & 0xFF;

  printf("[TX] Exception 0x%02X for function 0x%02X\n", exception_code, function_code);
  uart_write(uart0, response, 5);
}

static uint16_t get_ac_voltage(void) {
  return 2300; // 230.0 V, scale 0.1 V
}

static uint16_t get_ac_frequency(void) {
  return 5000; // 50.00 Hz, scale 0.01 Hz
}

static uint16_t get_ac_current_raw(const chip_state_t *chip) {
  uint16_t active_power = 0;
  if (chip->force_mode == 1) active_power = chip->charge_power;
  else if (chip->force_mode == 2) active_power = chip->discharge_power;
  if (active_power == 0) return 0;
  // I = P / V, scale 0.01 A
  return (uint16_t)((active_power / 230.0) * 100.0 + 0.5);
}

static int32_t get_ac_power(const chip_state_t *chip) {
  if (chip->force_mode == 1) return -(int32_t)chip->charge_power; // charging draws from grid
  if (chip->force_mode == 2) return (int32_t)chip->discharge_power; // discharging feeds grid
  return 0;
}
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

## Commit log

2026-09-15 Project 'Marstek ModBus Gateway' init
    [boot_closed.csv, boot_open.csv, close_cycle.csv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]
2026-09-15 Updated PCB and Wokwi
2026-09-16 Updated custom chip to mimic Marstek Modbus
    [Modbus Table - Modbus Datasheet.csv]
2026-09-16 Emulate charge/discharge values
2026-09-23 Added MQTT, Webserver and Led managers
    [boot_closed.csv, boot_open.csv, close_cycle.csv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]
2026-11-11 Updated schematic/PCB with dedicated power supply
2026-11-13 Fix PCB/schematic: switch modbus pins
2026-11-13 Fix PCB/Schematic
